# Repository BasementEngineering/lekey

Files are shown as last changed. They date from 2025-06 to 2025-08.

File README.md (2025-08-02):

# LEKeys
LEKeys or "LED Keys" is a little project that is supposed to help me with learning the piano.
It illuminates the key that has to be played next, with the ability to adjust the playback speed and mark certain sections that i want to practice.
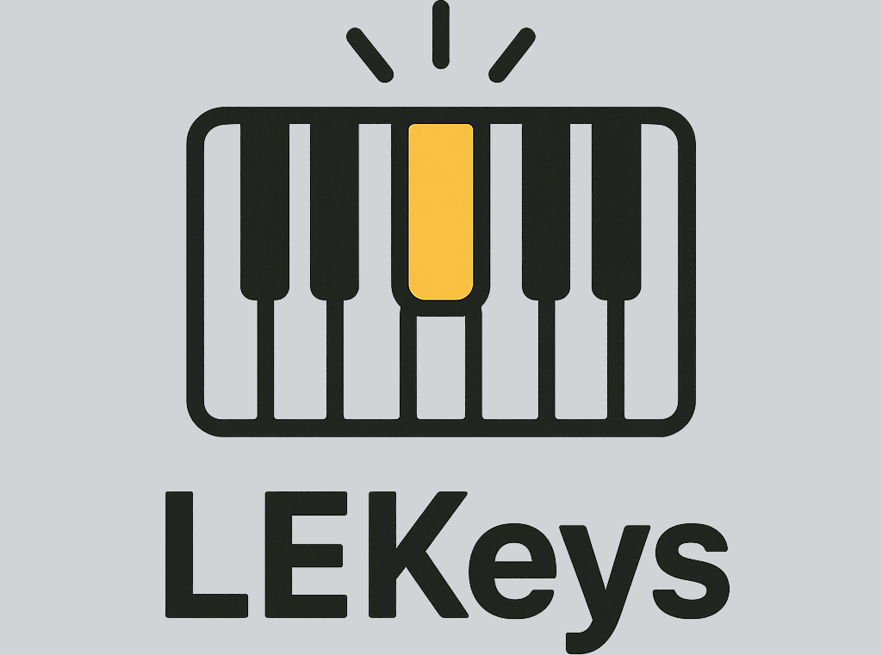
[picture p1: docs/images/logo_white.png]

## Hardware
The complete BOM can be found [here](ECAD/BOM.md).

## Features
- Put MIDI Songs on micro SD card
- Change placback Speed
- OLED 

## Pin Issues
- Rotary Encoder with push button requires 3 pins
- Possible Option is to connect it to a single Analog Input: https://www.elektormagazine.com/labs/rotary-encoder-on-a-single-mcu-pin
using an R-2R resistor network

## Controls
Control Sheme: Single Rotary Encoder with Push Button

Main Interactions
- Play/Pause
- Change Playback Speed
- Change MIDI Song
- Rewind and Forward

IOs
- Rotary Encoder: 2 Pins (16,0)
- Encoder push button: Analog Pin (A0)

Control actions:
- Play/Pause: Press Encoder Button
- Change Playback Speed: Rotate Encoder
- Change MIDI Song: Double Press Encoder Button
- Rewind and Forward: Rotate Encoder while pressing button

Section practice:
1. Set start with encoder, press to lock
2. Set end with encoder, press to lock
3. Press loop [loop, loop section, no looping]

(Settings for loop section should be saved to SD card, editable via PC)

## Aquiring MIDI Songs
- Use a MIDI Editor to create your own MIDI Songs
- Use a mp3 to MIDI converter e.g. [Transkun](https://github.com/Yujia-Yan/Transkun/tree/main)
To run it, you use the following command
```bash
transkun mp3_files/wonderwall.mp3 output.mid
```

However, so far, Transukun does not work. Installation via pip worked, but the program states 
"FileNotFoundError: [WinError 2] The system cannot find the file specified"
Although, the file is there. Entering an incorrect path throws a different error, stating the missing filename.
This is caused by ffmpeg not being installed or not being in the PATH.
Install ffmpeg and add it to the PATH.

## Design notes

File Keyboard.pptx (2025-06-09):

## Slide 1

+ 3 sec

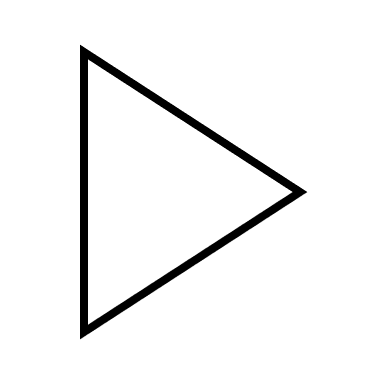
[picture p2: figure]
Play outline

MIDI Player 1

upcomming Notes

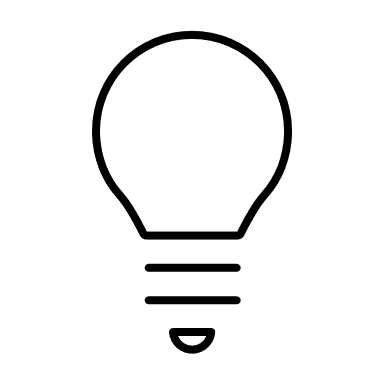
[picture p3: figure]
Lightbulb outline
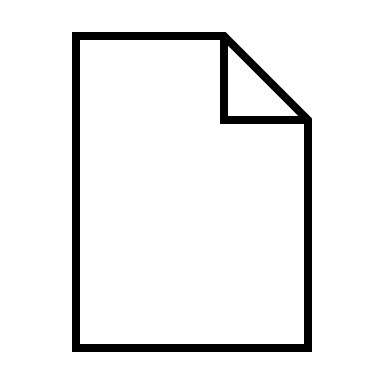
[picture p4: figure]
Paper outline

MIDI File

MIDI Player 2

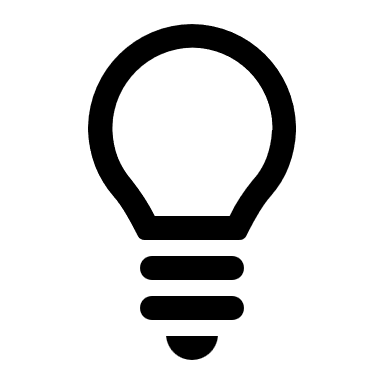
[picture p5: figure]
Lightbulb with solid fill

current Notes

foreshadowing

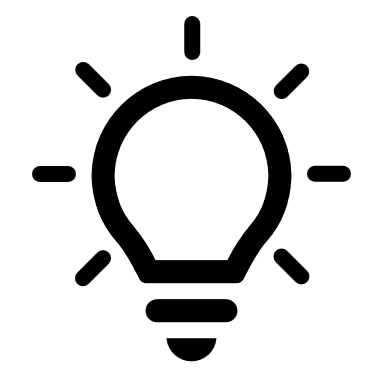
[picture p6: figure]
Lights On with solid fill

signaling

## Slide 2

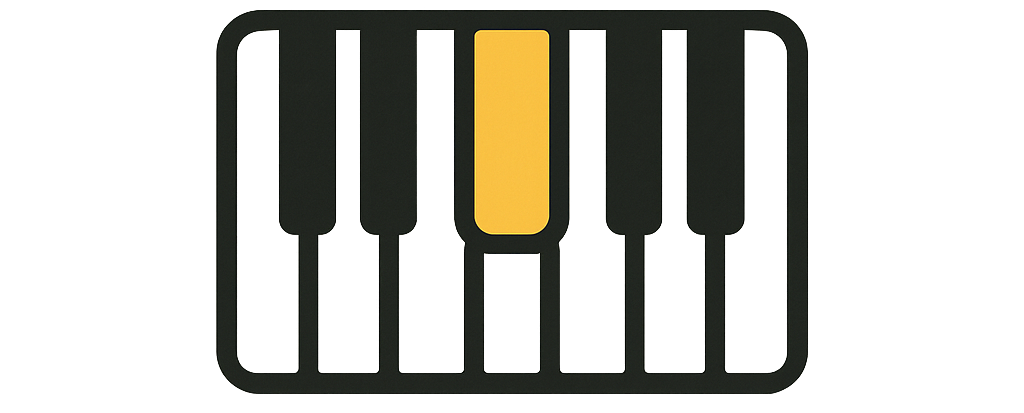
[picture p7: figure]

Playing: 1
128 BPM
1:00/2:10

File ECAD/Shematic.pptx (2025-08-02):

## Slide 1

Pinout and Pin Usage

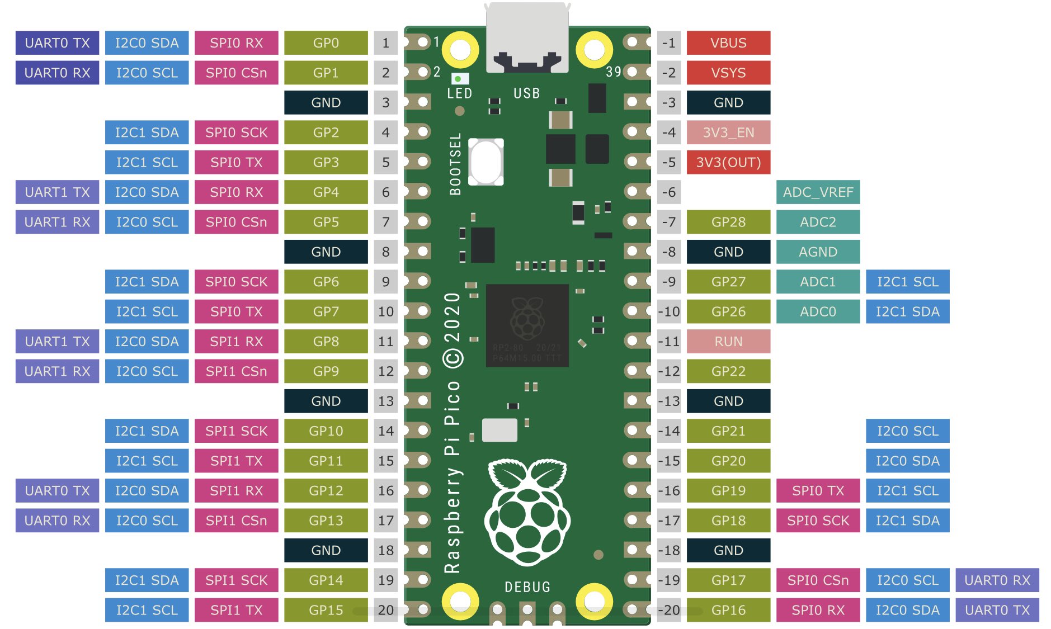
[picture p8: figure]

Raspberry Pi Pico

- OLED Display

Sw4

Sw3

Sw2

- SD Card

LED

Sw1

- Encoder SW

- SD Card

- Rotary sw Encoder + SW

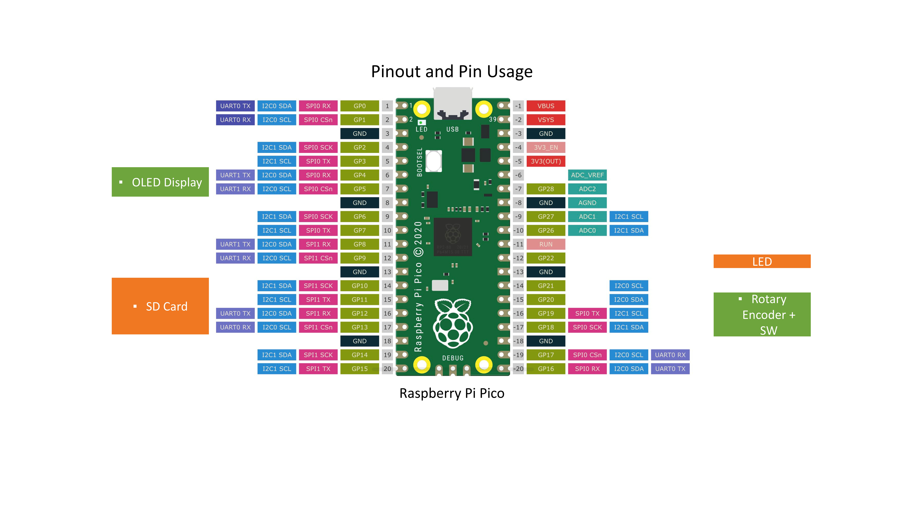
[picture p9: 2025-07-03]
docs/images/Pinout.jpg

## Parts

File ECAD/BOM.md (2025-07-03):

| Component | Description | Type/Part Number | Count | Link | Current Price (USD) |
|---|---|---|---|---|---|
| Microcontroller | Main control unit | Raspberry Pi Pico | 1 | [Reichelt](https://www.reichelt.de/de/de/shop/produkt/raspberry_pi_pico_rp2040_cortex-m0_microusb_header-305824) | 4.80 € |
| Push Button | Tactile switch | B3F-1000 | 4 | [Reichelt](hhttps://www.reichelt.de/de/de/shop/produkt/kurzhubtaster_printmontage_1_schliesser_6_x_6_x_4_3_mm-360041) | 0.33 € |
| Rotary Encoder | Incremental encoder | KY-040 | 1 | [Reichelt](https://www.reichelt.de/de/de/shop/produkt/entwicklerboards_-_drehwinkel-encoder_ky-040-282545) |  2,20 € |
| Display | 0,96" OLED display | SSD1306 | 1 | [Reichelt](https://www.reichelt.de/de/de/shop/produkt/entwicklerboards_-_display_0_96_oled-display_ssd1306-372107) | 8.85 €  |
| SD Adapter | MicroSD card adapter | MicroSD Adapter  | 1 | [MicroSD Adapter](https://www.reichelt.de/de/de/shop/produkt/entwicklerboards_-_breakout-board_fuer_microsd-karten-266045) | 1,55 € |
| LED Strip | ADressable RGB LEDs 60LEDs/m 5V | WS2812B | 1 | [WS2812B LED Strip](https://amzn.eu/d/gXoEgu9) | 27.99 € |

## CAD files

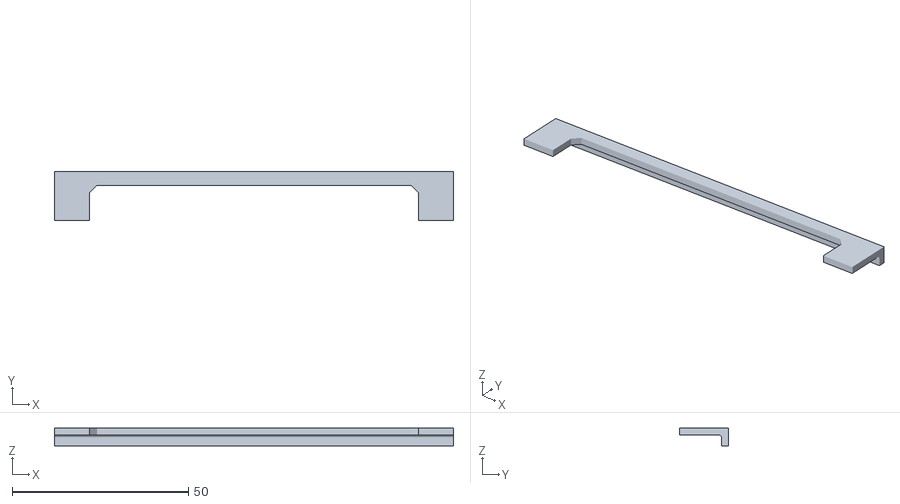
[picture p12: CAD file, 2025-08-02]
CAD/Controller/Stabilizer.stl
113.2 x 14.0 x 5.00

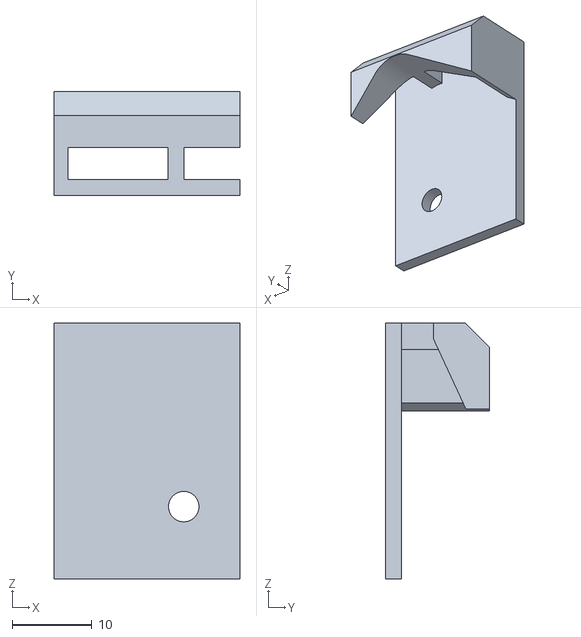
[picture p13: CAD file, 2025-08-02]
CAD/Light_guide_end.stl
23.2 x 13.0 x 32.0

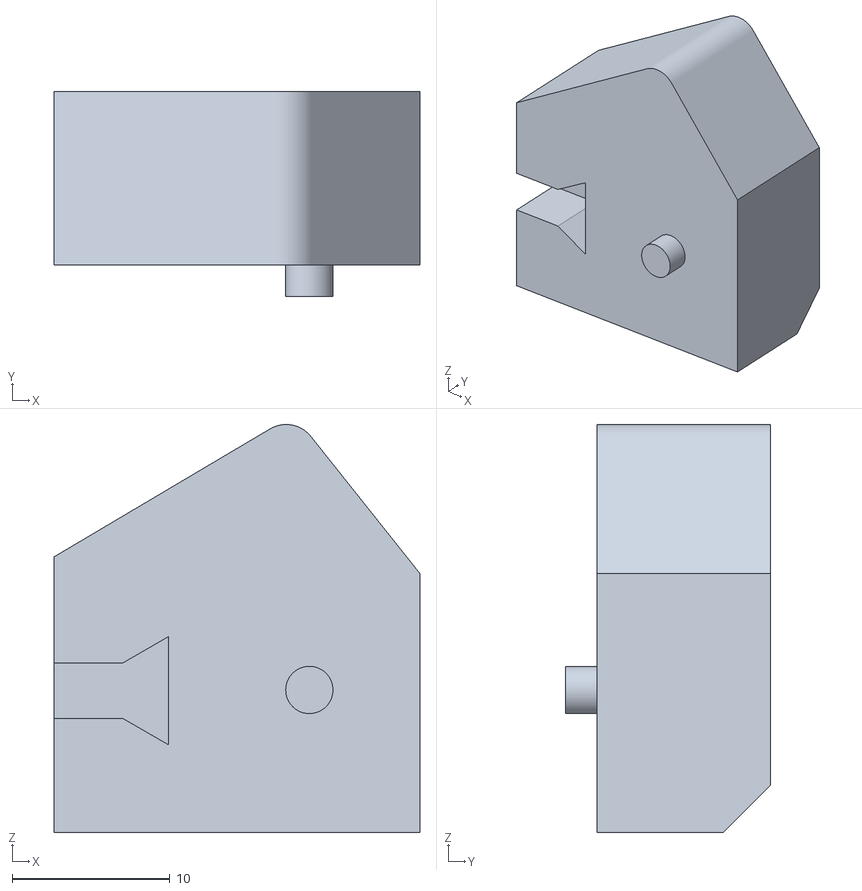
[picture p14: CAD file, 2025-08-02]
CAD/Back_piece_end.stl
23.2 x 13.0 x 25.9

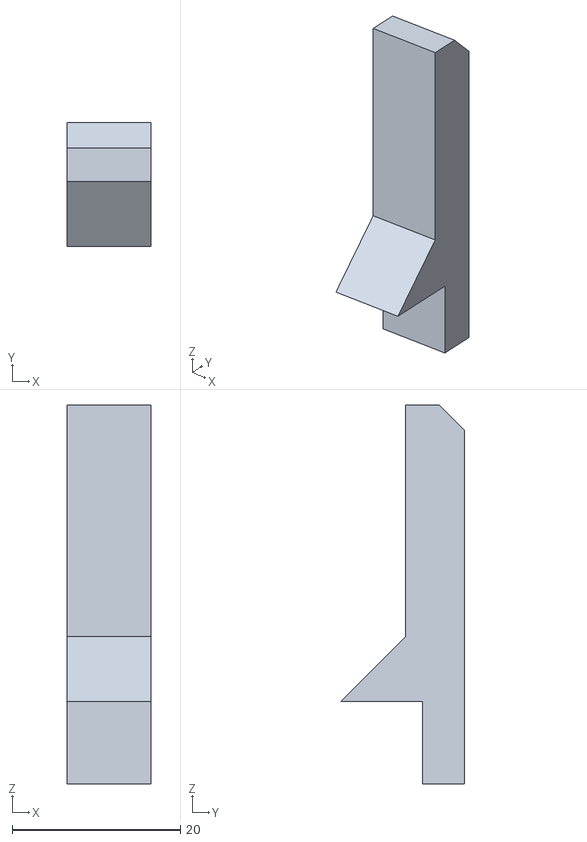
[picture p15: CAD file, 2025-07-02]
CAD/Controller/Black_Key.stl
10.0 x 14.7 x 45.0

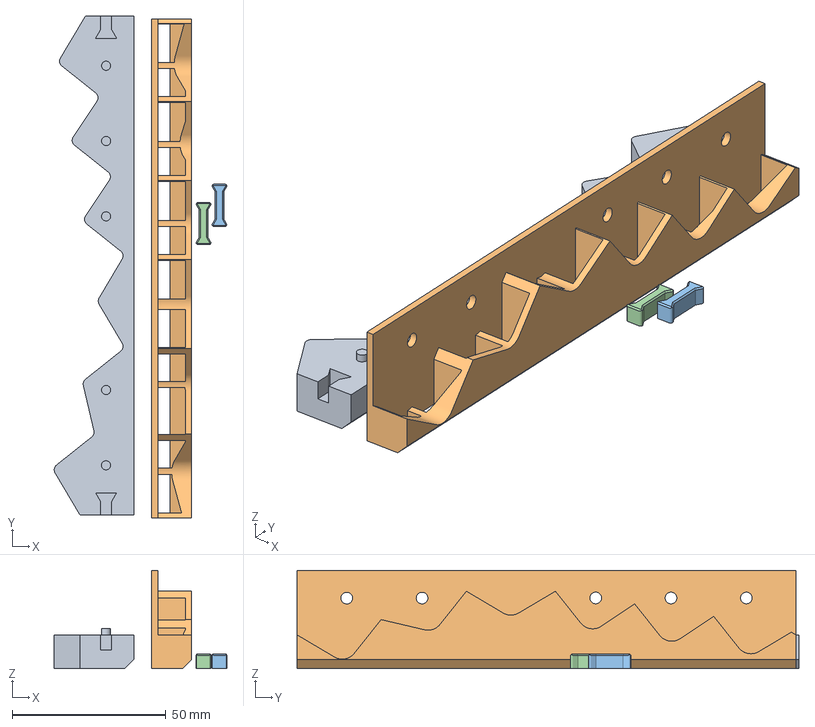
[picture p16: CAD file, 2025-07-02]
CAD/AA8_LEKeys_LightBar.3mf
56.2 x 163.3 x 32.0 mm
Back_piece.stl
Light_guide.stl
Connector.stl
Connector.stl(1)

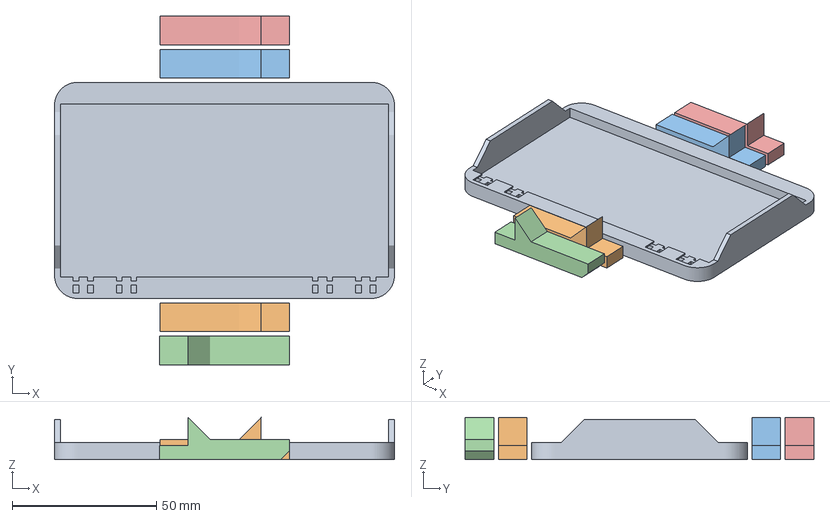
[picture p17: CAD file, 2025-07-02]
CAD/Controller/PrintInBlack.3mf
118.0 x 121.0 x 14.7 mm
Bottom.stl
Black_Key.stl
Black_Key.stl(1)
Black_Key.stl(2)
Black_Key.stl(3)

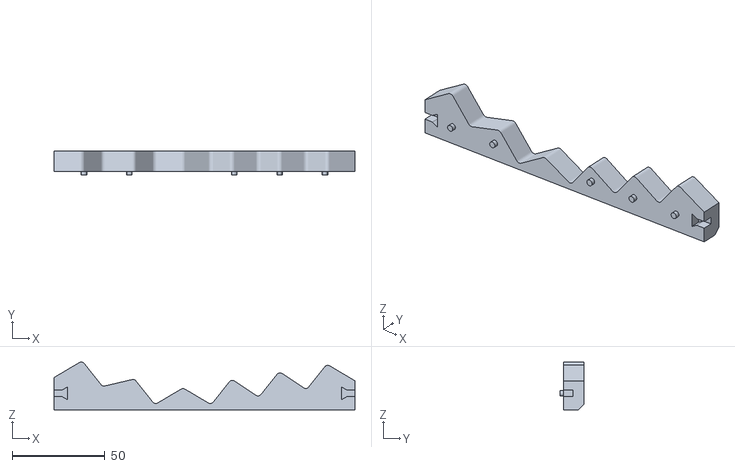
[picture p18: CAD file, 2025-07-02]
CAD/Back_piece.stl
162.4 x 13.0 x 25.9

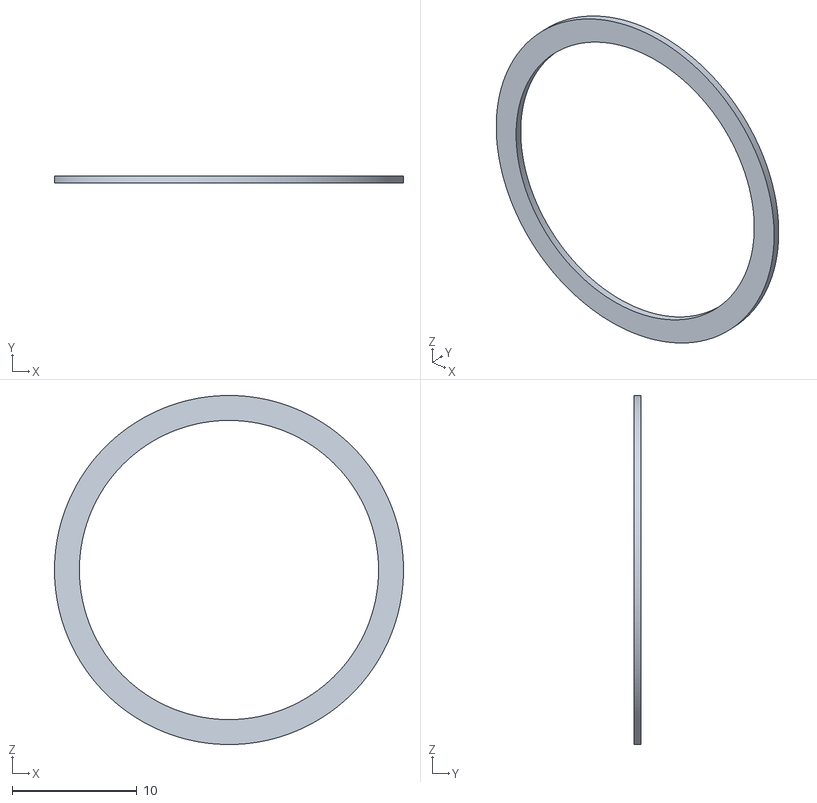
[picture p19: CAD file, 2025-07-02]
CAD/Controller/Decal_Ring.stl
28.0 x 0.6 x 28.0

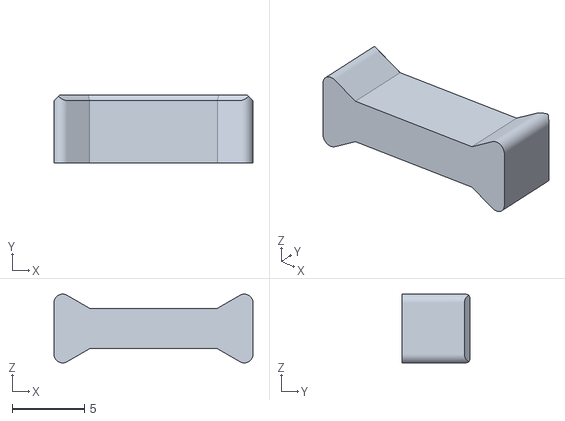
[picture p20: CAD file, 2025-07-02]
CAD/Connector.stl
13.8 x 4.75 x 4.78

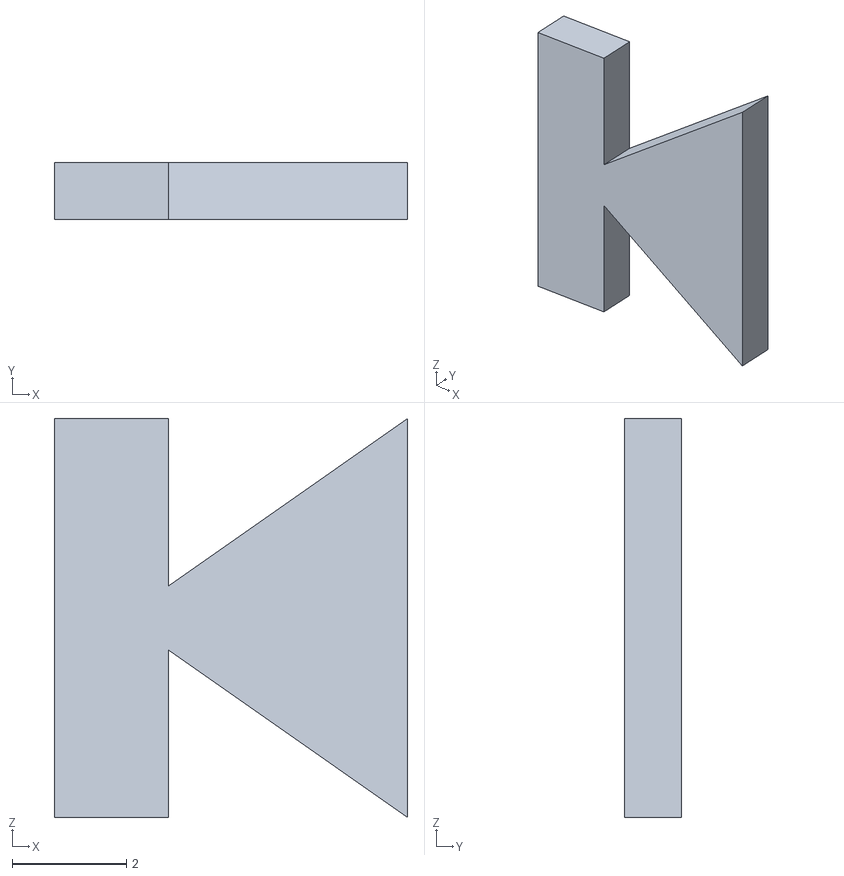
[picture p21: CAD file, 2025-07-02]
CAD/Controller/Decal_Skip.stl
6.20 x 1.00 x 7.00

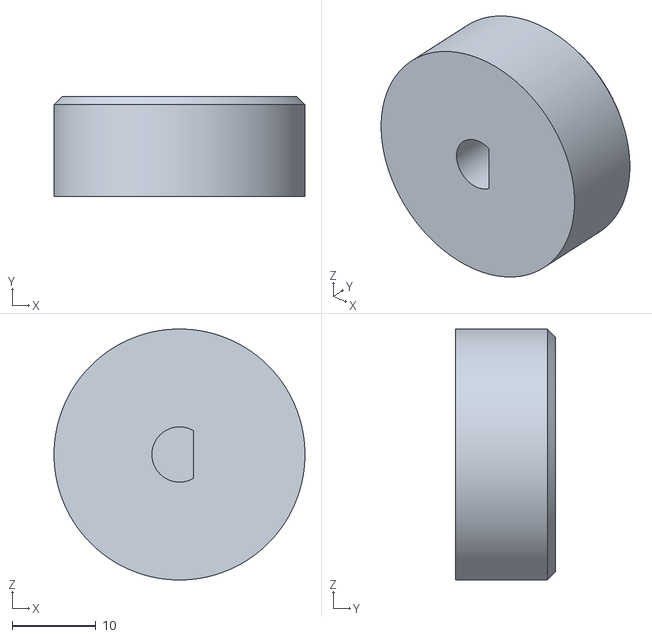
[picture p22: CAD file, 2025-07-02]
CAD/Controller/Knob.stl
30.0 x 12.0 x 30.0

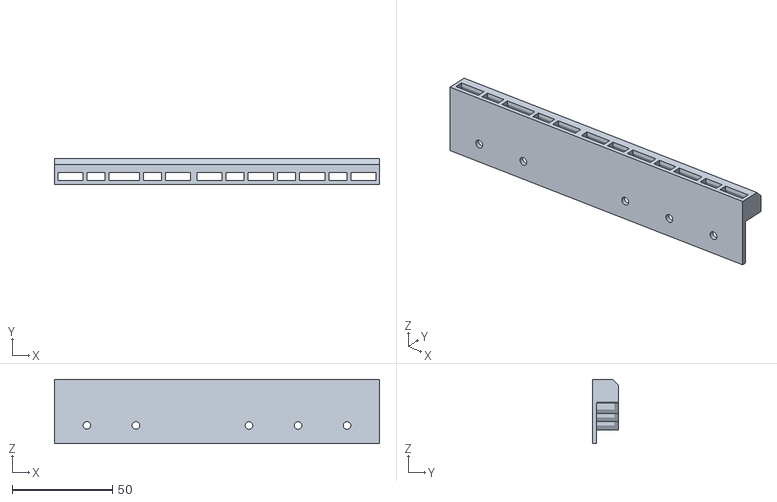
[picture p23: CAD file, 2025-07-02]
CAD/Light_guide.stl
162.4 x 13.0 x 32.0

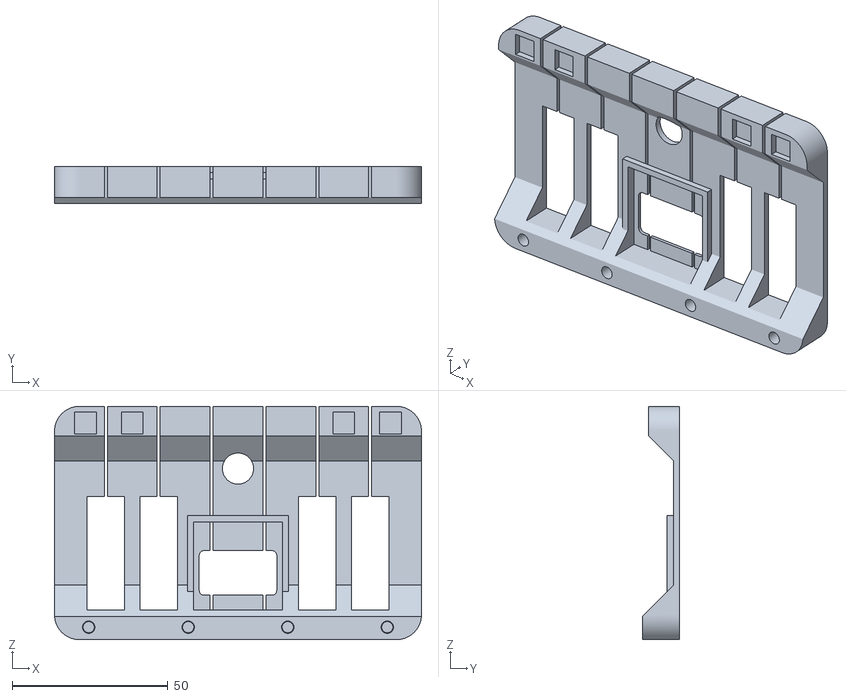
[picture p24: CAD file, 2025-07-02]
CAD/Controller/White_Keys.stl
118.0 x 12.0 x 75.0

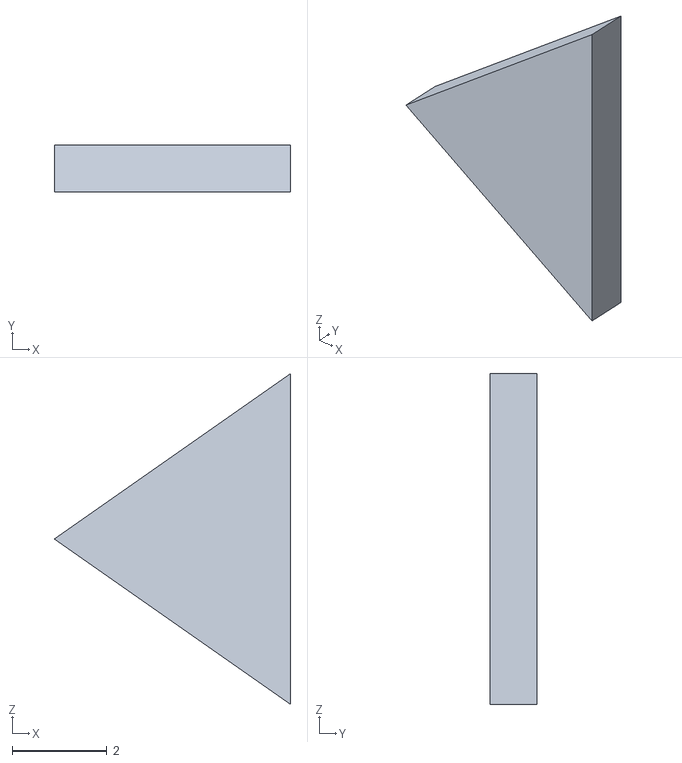
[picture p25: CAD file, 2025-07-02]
CAD/Controller/Decal_Back.stl
5.00 x 1.00 x 7.00

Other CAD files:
CAD/Controller/Bottom.stl

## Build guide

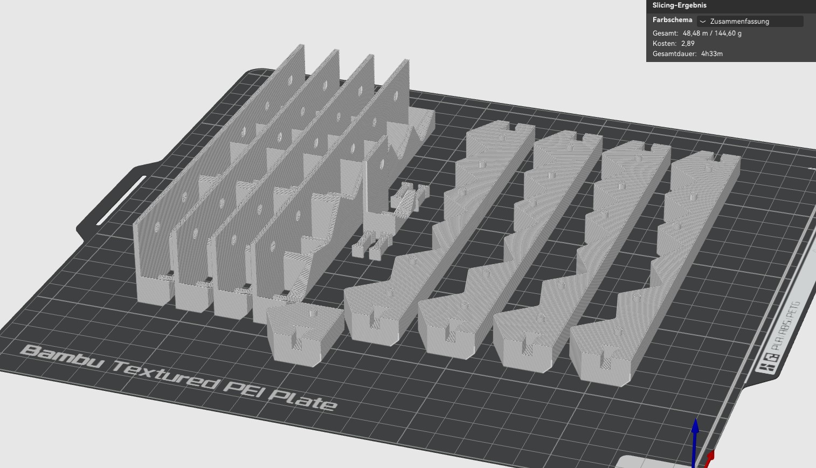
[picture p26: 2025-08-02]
docs/images/led_bar/printing.jpg

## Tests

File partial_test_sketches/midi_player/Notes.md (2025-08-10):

# MY Player Notes

Time syncing and keeping: custom parsing

## Implementation of looking into the future
Option A: External tick generator parallel to the one inside each MD_Track
- "Easy" to implement without accessing internal MD_Track workings. 
- Might cause the timers to go out of sync.
- Track has to be played until + 4 bars and captured.

    // I need to look 4 bars into the future in the file to enable looping and to be able to highlight the keys one bar ahead.
    // This is tricky to do as midi events come as a stream of events with a start and an unknown end. 
    // To find the end of a key press you actually have to parse all the way to the key up event.
    // A pointer to this structure type is passed to the callback function registered using setMidiHandler().
    // No note is longer than 4 bars, so if i look 4 bars into the future i should know the duration of every note.

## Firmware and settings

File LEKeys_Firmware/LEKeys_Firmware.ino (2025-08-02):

#include <SdFat.h>
#include <MD_MIDIFile.h>

#include "led_output.h"
#include "display_output.h"

#include "pins.h"

#include "encoder_input.h"
#include "button_input.h"

int playback_speed_bpm = 60; // Playback speed in beats per minute
int choosen_tune = 0; // Index of the currently chosen tune

int bpm = 120; // Beats per minute
int beatsPerBar = 4; // Beats per measure
int currentBeat = 0; // Current beat in the measure
int currentBar = 0; // Current bar in the song
int maxBars = 120; // Total number of bars in the song
int loopLength = 3; // Length of the loop in bars
int loopStart = 4;


enum class DeviceState {
    INITIALIZING1,
    INITIALIZING2,
    PAUSED,
    PLAYING
};
DeviceState currentDeviceState = DeviceState::INITIALIZING1;
unsigned long lastStateChange = 0;

Encoder_Input encoder(ENCODER_CLK_PIN, ENCODER_DT_PIN);
Button_Input buttonInput(ENCODER_SW_PIN, 20); // Debounce delay 50ms
LedStrip strip(LED_PIN); // Create a LedStrip object with 61 LEDs (5 octaves + 1 for the highest note)
Display_Output display;

SdFat	SD;
MD_MIDIFile SMF;
MD_MIDIFile SMF2; // Second MIDI file object that is going to point to the same file but 5 seconds in the future

// Timing Notes
// There are multiple things
// ticks - simply counts the number of ticks since the last event
// ticksPerQuarterNote - the number of ticks per quarter note, which is used to calculate the tempo
// timeSignature - the time signature of the MIDI file, e.g. 3/4 which is used to calculate the number of ticks per beat
// My LED have to foreshadow the next note and light it up when the note is played
// To do foreshadow the next note, I need to know the current note and the next note
// The MIDI file is played in a loop, so I need to know the current position in the file but also the next position in the future.
// Specifically a sensible future could be a full beat e.g. 4/4 in the future.
// My idea is to use the SMF2 object to point to the same file but one beat step in the future.

// The files in the tune list should be located on the SD card 
// or an error will occur opening the file and the next in the 
// list will be opened (skips errors).
const char *loopfile = "wonderwall.mid";  // simple and short file
int max_files = 10;
char **file_list = NULL; // Pointer to an array of file names

// Function Prototypes
void runStateMachine();
void switchState(DeviceState newState);
void fillFileListFromSD();
void setupPlayer();
void midiCallback(midi_event *pev);
void midiCallback2(midi_event *pev);
void main_button_isr();
void setupLeds();

void setup() {
    Serial.begin(9600);
    Serial.println("Starting Keyboard");
    delay(1000);
    
    display.begin(); // Initialize the user interface
    switchState(DeviceState::INITIALIZING1); // Set initial state to INITIALIZING1
    runStateMachine(); // Run the state machine to update the display

    setupLeds(); // Setup the LED strip
    
    #define SPI_SPEED SD_SCK_MHZ(4) //Does not work without that
    if (!SD.begin(SD_CS_PIN, SPI_SPEED))
    {
        Serial.println("\nSD init fail!");
        while (true) ;
    }

    fillFileListFromSD(); // Fill the file list from the SD card
    setupPlayer(); // Setup the MIDI player

    encoder.begin();
    buttonInput.begin(main_button_isr);

    display.begin();
    display.update(); // Initial display update

    Serial.println("Ready");
}

unsigned long tick_length = 100;
unsigned long last_tick = 0;

unsigned long current_tick = 0;
int last_bpm = 0; // Last BPM value to avoid unnecessary updates
bool rewinded = false; // Flag to indicate if the file has been rewound

void loop() {
     handleBpmChange(); // Handle BPM changes

    if (!SMF2.isEOF())
    {
      SMF2.getNextEvent();
    }

    if(!rewinded && millis() > 500){
      SMF2.restart(); // Rewind the second MIDI file
      rewinded = true; // Set the flag to true to avoid rewinding again
      Serial.println("MIDI file rewound");
    }
    runStateMachine(); // Run the state machine to update the display and handle events
// Remove encoder.process() from loop and use a timer interrupt instead
}

////// STATE MACHINE FUNCTIONS //////
void runStateMachine() {
    switch (currentDeviceState) {
    case DeviceState::INITIALIZING1:
        if (millis() - lastStateChange > 1000) { // Update every second
            switchState(DeviceState::INITIALIZING2); // Switch to INITIALIZING2 after 1 second
        }
        break;
    case DeviceState::INITIALIZING2:
        if (millis() - lastStateChange > 1000) { // Update every second
            switchState(DeviceState::PLAYING); // Switch to PAUSED after 1 second
        }
        break;
    case DeviceState::PAUSED:
        
        break;
    case DeviceState::PLAYING:
        if (millis() - last_tick > 200) { // Update every 200 milliseconds
            SMF.getNextEvent(); // Process the next MIDI event
            display.showPlaying(bpm, (char *)loopfile, true, currentBar, maxBars, currentBeat, loopStart, loopLength);
            last_tick = millis();
        }
        break;
    }
}

void switchState(DeviceState newState) {
  Serial.print("Switching state from ");
  Serial.println(static_cast<int>(currentDeviceState));
  Serial.print(" to ");
  Serial.println(static_cast<int>(newState));

  currentDeviceState = newState;
  lastStateChange = millis(); // Reset the timer when switching states

  switch (newState) {
    case DeviceState::INITIALIZING1:
      display.showInitializing(1); // Show initializing screen 1
      break;
    case DeviceState::INITIALIZING2:
      display.showInitializing(0); // Show initializing screen 2
      break;
    case DeviceState::PAUSED:
      break;
    case DeviceState::PLAYING:
      display.showPlaying(bpm, (char *)loopfile, true, currentBar, maxBars, currentBeat, loopStart, loopLength); // Show playing screen
      break;
  }
}

////// SETUP FUNCTIONS //////
void setupPlayer(){
 // Initialize MIDIFile
    SMF.begin(&SD);
    SMF2.begin(&SD);
    SMF.setMidiHandler(midiCallback);
    SMF2.setMidiHandler(midiCallback2);
    SMF.looping(true);
    SMF2.looping(true);

    int err;
    err = SMF.load(loopfile);
  if (err != MD_MIDIFile::E_OK)
  {
    Serial.println("SMF load Error ");
    
    while (true);
  }

    err = SMF2.load(loopfile);
  if (err != MD_MIDIFile::E_OK)
  {
    Serial.println("SMF2 load Error "); 
    while (true);
  }
    Serial.print("SMF loaded: ");
    Serial.println(loopfile);
}

void setupLeds() {
    strip.begin(); // Initialize the LED strip
    strip.runTestSequence(); // Run the test sequence to check if the LEDs are working
    strip.setMainColor(strip.Color(0, 0, 255)); // Set main color to blue
    strip.setForeshadowColor(strip.Color(127, 0, 0)); // Set foreshadow color to dim red
}

void fillFileListFromSD() {
  Serial.println("Filling file list from SD...");
  file_list = new char*[max_files]; // Allocate memory for 10 files
  //make sure all pointers are initialized to NULL
  for (int i = 0; i < max_files; i++) {
    file_list[i] = NULL;
  }

  int count = 0;
  File root = SD.open("/");
  File file = root.openNextFile();
  while (file) {
    Serial.print("Found: ");
    if (file.isDirectory()) {
      Serial.println("Skipping directory.");
      file.close();
      file = root.openNextFile();
      continue;
    }
    char filename[21];
    file.getName(filename, 20);
    filename[20] = '\0';
    // Only add files ending with ".mid" (case-insensitive)
    int len = strlen(filename);
    if (len >= 4 && 
        (strcasecmp(filename + len - 4, ".mid") == 0)) {
      if (count < max_files) {
        char *stored = new char[len + 1];
        strcpy(stored, filename);
        file_list[count] = stored;
        Serial.print("Added to list: ");
        Serial.println(file_list[count]);
        count++;
      } else {
        Serial.println("Max file count reached, skipping remaining files.");
      }
    } else {
      Serial.println("Not a .mid file, skipping.");
    }
    file.close();
    file = root.openNextFile();
  }
  file_list[count] = NULL; // Null-terminate the list
  Serial.print("Total .mid files added: ");
  Serial.println(count);
}

/////// INPUT HANDLING FUNCTIONS //////
void handleBpmChange() {
    if(last_bpm != playback_speed_bpm) {
        last_bpm = playback_speed_bpm; // Update last BPM
        tick_length = 60000 / playback_speed_bpm; // Calculate new tick length based on BPM
        Serial.print("Tick length updated to: ");
        Serial.println(tick_length);
        SMF.setTempo(playback_speed_bpm); // Update the tempo in the MIDI file
        SMF2.setTempo(playback_speed_bpm); // Update the tempo in the second MIDI file
    }
}

////// MIDI CALLBACK FUNCTIONS //////
void midiCallback2(midi_event *pev) {
    Serial.print("MIDI Event 2: ");
    Serial.print("Track: ");
    Serial.println(pev->track);
    Serial.print("Channel: ");
    Serial.println(pev->channel);
      Serial.println(" Data");
  for (uint8_t i=0; i<pev->size; i++)
  {
     Serial.print(pev->data[i],HEX);
     Serial.print(" ");
  }

  if(pev->data[0] == 0x90) { // Note On event
    uint8_t midi_note = pev->data[1]; // MIDI note number
    strip.light(midi_note); // Light the note
    Serial.print("Lit note: ");
    Serial.println(midi_note);
  } else if (pev->data[0] == 0x80) { // Note Off event
    uint8_t midi_note = pev->data[1]; // MIDI note number
    strip.clear(midi_note); // Clear the strip for this note
    Serial.print("Cleared note: ");
    Serial.println(midi_note);
  }
  Serial.println();
}

void midiCallback(midi_event *pev) {
    Serial.print("MIDI Event: ");
    Serial.print("Track: ");
    Serial.println(pev->track);
    Serial.print("Channel: ");
    Serial.println(pev->channel);
      Serial.println(" Data");
  for (uint8_t i=0; i<pev->size; i++)
  {
     Serial.print(pev->data[i],HEX);
     Serial.print(" ");
  }

  if(pev->data[0] == 0x90) { // Note On event
    uint8_t midi_note = pev->data[1]; // MIDI note number
    strip.foreshadow(midi_note); // Foreshadow the note
    Serial.print("Lit note: ");
    Serial.println(midi_note);
  } else if (pev->data[0] == 0x80) { // Note Off event
    
  }
  Serial.println();
}

void main_button_isr(){
  buttonInput.handleInterrupt();
}

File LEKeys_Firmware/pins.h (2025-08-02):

#define LED_PIN 22 // Pin for the LED strip
#define SD_CS_PIN 13 // Pin for the SD card chip select
#define OLED_SDA_PIN 4 // Pin for the OLED display SDA
#define OLED_SCL_PIN 5 // Pin for the OLED display SCL

#define ENCODER_CLK_PIN 15 // Pin for the rotary encoder CLK
#define ENCODER_DT_PIN 14 // Pin for the rotary encoder DT

#define ENCODER_SW_PIN 20 // Pin for the rotary encoder switch

//#define SD_MISO 

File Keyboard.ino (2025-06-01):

#include "leds.h"

#include <SdFat.h>
#include <MD_MIDIFile.h>

#define SD_CS_PIN 16 // Chip select pin for SD card
#define LED_PIN    0

LedStrip strip(LED_PIN); // Create a LedStrip object with 61 LEDs (5 octaves + 1 for the highest note)

SdFat	SD;
MD_MIDIFile SMF;

// The files in the tune list should be located on the SD card 
// or an error will occur opening the file and the next in the 
// list will be opened (skips errors).
const char *loopfile = "6LEDS.MID";  // simple and short file

void midiCallback(midi_event *pev) {
    Serial.print("MIDI Event: ");
    Serial.print("Track: ");
    Serial.println(pev->track);
    Serial.print("Channel: ");
    Serial.println(pev->channel);
      Serial.println(" Data");
  for (uint8_t i=0; i<pev->size; i++)
  {
     Serial.print(pev->data[i],HEX);
     Serial.print(" ");
  }

  if(pev->data[0] == 0x90) { // Note On event
    uint8_t midi_note = pev->data[1]; // MIDI note number
    strip.foreshadow(midi_note); // Foreshadow the note
    strip.light(midi_note); // Light the note
    Serial.print("Lit note: ");
    Serial.println(midi_note);
  } else if (pev->data[0] == 0x80) { // Note Off event
    uint8_t midi_note = pev->data[1]; // MIDI note number
    strip.clear(); // Clear the strip for this note
    Serial.print("Cleared note: ");
    Serial.println(midi_note);
  }
  Serial.println();
}

void setup() {
    Serial.begin(9600);
    Serial.println("Starting Keyboard");
    strip.begin(); // Initialize the LED strip
    strip.setMainColor(strip.Color(0, 0, 255)); // Set main color to white
    strip.setForeshadowColor(strip.Color(127, 0, 0)); // Set foreshadow color to dim white

    #define SPI_SPEED SD_SCK_MHZ(4) //Does not work without that
    if (!SD.begin(16, SPI_SPEED))
    {
        Serial.println("\nSD init fail!");
        while (true) ;
    }

    // Initialize MIDIFile
    SMF.begin(&SD);
    SMF.setMidiHandler(midiCallback);
    SMF.looping(true);

    int err;
    err = SMF.load(loopfile);
  if (err != MD_MIDIFile::E_OK)
  {
    Serial.println("SMF load Error ");
    
    while (true);
  }

    Serial.println("Ready");
}

unsigned long tick_length = 100;
unsigned long last_tick = 0;

unsigned long current_tick = 0;

void loop() {

    if (millis() - last_tick >= tick_length) {
        last_tick = millis();
        current_tick++;
    }

      // play the file
  if (!SMF.isEOF())
  {
    SMF.getNextEvent();
  }
}

/*void get_chord_from_serial() {
    if (Serial.available()) {
        String input = Serial.readStringUntil('\n');
        input.trim();
        String notes[LED_COUNT];
        int noteCount = 0;

        // Split input by commas
        int startIndex = 0;
        for (int i = 0; i < input.length(); i++) {
            if (input[i] == ',') {
                notes[noteCount++] = input.substring(startIndex, i);
                startIndex = i + 1;
            }
        }
        // Add last note
        if (startIndex < input.length()) {
            notes[noteCount++] = input.substring(startIndex);
        }

        lightNotes(notes, noteCount);
    }
}*/

/*// Map notes to LED indices (C=0, D=1, ..., B=11)
const char* noteNames[12] = {
    "C","C#", "D", "D#", "E", "F", "F#", "G", "G#", "A", "A#", "B"
};

int hex_string_to_int(const String& hexString) {
    int value = 0;
    for (int i = 0; i < hexString.length(); i++) {
        char c = hexString.charAt(i);
        if (c >= '0' && c <= '9') {
            value = value * 16 + (c - '0');
        } else if (c >= 'A' && c <= 'F') {
            value = value * 16 + (c - 'A' + 10);
        } else if (c >= 'a' && c <= 'f') {
            value = value * 16 + (c - 'a' + 10);
        }
    }
    Serial.print("Hex string: ");
    Serial.print(hexString);
    Serial.print(" converted to int: ");
    Serial.println(value);
    return value;
}

void get_midi_command_from_serial()
{
    if (Serial.available()) {
        String input = Serial.readStringUntil('\n');
        input.trim();
        Serial.print("Received MIDI command: ");
        Serial.println(input);
        //The midi command is made up of three parts: command, note, velocity
        //Those are received in 3 bytes, so we can split the input by spaces
        String parts[3];
        int partCount = 0;
        int startIndex = 0;
        for (int i = 0; i < input.length(); i++) {
            if (input[i] == ' ') {
                parts[partCount++] = input.substring(startIndex, i);
                startIndex = i + 1;
            }
        }
        int midi_note = -1; // Default to an invalid note
        // Add last part
        if (startIndex < input.length()) {
            parts[partCount++] = input.substring(startIndex);
        }
        // Parse the parts
        if (partCount >= 2) {
            String command = parts[0];
            Serial.print("midi note before: ");
            Serial.println(parts[1]);

            midi_note = hex_string_to_int(parts[1]); // Convert the note from hex string to int
            Serial.print("Command: ");
            Serial.println(command);
            Serial.print("MIDI Note: ");
            Serial.println(midi_note);
        } else {
            Serial.println("Invalid MIDI command format. Please use 'command note velocity'.");
        }

        if (midi_note >= 0 && midi_note < 128) { // Valid MIDI note range
            strip.foreshadow(midi_note); // Foreshadow the note
            strip.light(midi_note); // Light the note
            Serial.print("Lit note: ");
            Serial.println(noteNames[midi_note % 12]);
        } else {
            Serial.println("Invalid MIDI note. Please enter a value between 0 and 127.");
        }
    }
}
*/

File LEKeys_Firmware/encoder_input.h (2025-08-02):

#ifndef ENCODER_INPUT_H
#define ENCODER_INPUT_H

#include <Arduino.h>

class Encoder_Input {
public:
    Encoder_Input(uint8_t clkPin, uint8_t dtPin)
        : clkPin(clkPin), dtPin(dtPin), position(0), lastClkState(HIGH) {}

    void begin() {
        pinMode(clkPin, INPUT_PULLUP);
        pinMode(dtPin, INPUT_PULLUP);
        lastClkState = digitalRead(clkPin);
        instance = this;
        attachInterrupt(digitalPinToInterrupt(clkPin), isr, CHANGE);
    }

    // Returns the number of steps since last call, resets internal counter
    int read() {
        noInterrupts();
        int delta = position;
        position = 0;
        interrupts();
        return delta;
    }

private:
    volatile int position;
    uint8_t clkPin;
    uint8_t dtPin;
    volatile int lastClkState;

    static Encoder_Input* instance;

    static void isr() {
        if (instance) instance->handleInterrupt();
    }

    void handleInterrupt() {
        int clkState = digitalRead(clkPin);
        int dtState = digitalRead(dtPin);

        bool clkRising = (clkState == HIGH && lastClkState == LOW);
        bool clkFalling = (clkState == LOW && lastClkState == HIGH);

        if (clkRising) {
            if (dtState == LOW) {
                position--;
            } else {
                position++;
            }
        } else if (clkFalling)
        {
            if(dtState == LOW) {
                position++;
            } else {
                position--;
            }
        }

        lastClkState = clkState;
        /*if (clkState != lastClkState) {
            if (clkState == LOW) {
                if (dtState != clkState) {
                    position++;
                } else {
                    position--;
                }
            }
            lastClkState = clkState;
        }*/
    }
};

// Static member initialization
Encoder_Input* Encoder_Input::instance = nullptr;

#endif // ENCODER_INPUT_H

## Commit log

2025-06-08 Added schematics and thoughts on how to implement the hardware
2025-06-11 Added an OLED Display and a rotary encoder
2025-07-02 Added 3D Printing files
    [AA8_LEKeys_LightBar.3mf, Back_piece.stl, Black_Key.stl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]
2025-07-03 Added a Bill of Materials
2025-07-03 Made the SD Card work and enabled midi playback on the LED strip. Issue: Blocks encoder code
    [LEKeys_Firmware.ino, led_output.h, led_output.ino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]
2025-07-04 Implemented interrupt based encoder and push button contorls
2025-08-02 Added all necessary 3D printing files
    [Back_piece_end.stl, Light_guide_end.stl, Stabilizer.stl]
2025-08-02 Added interrupt based encoder code
2025-08-10 Intorduced a MyPlayer class that is supposed to encapsulate file playback and handle anything related to track numbers. The class is a static singleton to allow functions to be used as callbacks for 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
